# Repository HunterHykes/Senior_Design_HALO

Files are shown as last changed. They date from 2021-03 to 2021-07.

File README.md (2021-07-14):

# Senior_Design_HALO

This is the repository for the Hard Hat Ambient Liability Observer (H.A.L.O.) I assisted in developing for my senior design project at the University of Akron from Spring 2020 - Spring 2021.

<p align="center">
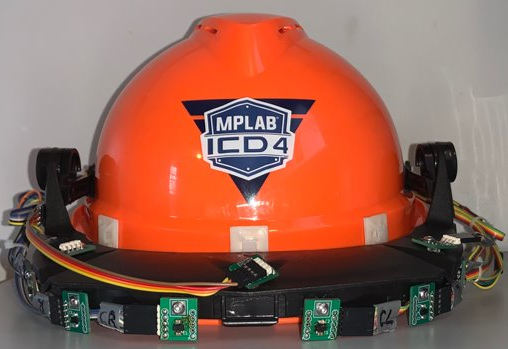
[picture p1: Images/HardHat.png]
  
  
<p align="center">H.A.L.O. attached to a hard hat.</p>
</p>

<p align="center">
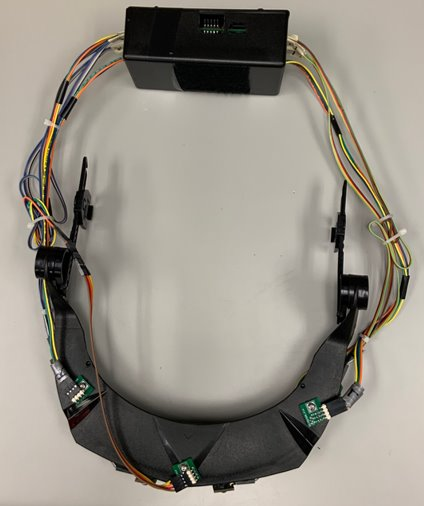
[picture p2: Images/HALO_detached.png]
  
  
<p align="center">H.A.L.O. detached from a hard hat.</p>
</p>

## What the H.A.L.O. Does
This product is a hard hat attachment which utilizes six time-of-flight (ToF) sensors to detect hazards within a 1.5m radius from the wearer's head with a 150° field of view.

<p align="center">
  
  
<p align="center">H.A.L.O. Time-of-Flight Board.</p>
</p>

Dependent on the distance between the user and the hazard, some RGB LEDs placed near the brim of the hard hat will turn on and change hue from yellow to red as objects approach. This enhances the awareness of the user of potential hazards.

<p align="center">
  
  
<p align="center">H.A.L.O. RGB LED Board.</p>
</p>

In the event that the user hits their head either from a collision from walking or perhaps from slipping and falling, an on-board accelerometer will detect the impact severity.

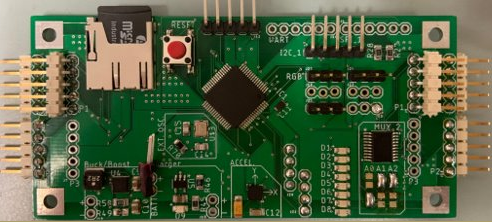
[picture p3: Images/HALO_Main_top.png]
H.A.L.O. Main Board (top).

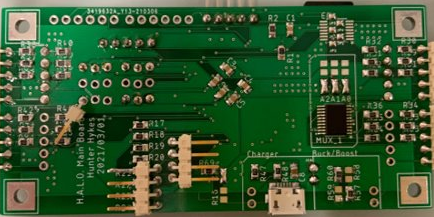
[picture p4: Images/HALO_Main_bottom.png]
H.A.L.O. Main Board (bottom).


If this impact is determined to pose a concussion threat to the user, the accelerometer data is logged to a .csv file on a micro-SD card, which can then be used to assess health-related concerns.

## Images

<p align="center">
  
  
<p align="center">H.A.L.O. being worn by myself.</p>
</p>

<!--- ![H.A.L.O. attached to a hard hat.](https://github.com/HunterHykes/Senior_Design_HALO/raw/main/Images/HardHat.png) --->
<!--- ![H.A.L.O. detached from a hard hat.](https://github.com/HunterHykes/Senior_Design_HALO/raw/main/Images/HALO_detached.png) --->
<!--- ![H.A.L.O. being worn by myself.](https://github.com/HunterHykes/Senior_Design_HALO/raw/main/Images/HALO.JPG) --->
<!--- ![H.A.L.O. Time-of-Flight Board.](https://github.com/HunterHykes/Senior_Design_HALO/raw/main/Images/HALO_ToF.png) --->
<!--- ![H.A.L.O. RGB LED Board.](https://github.com/HunterHykes/Senior_Design_HALO/raw/main/Images/HALO_RGB.png) --->

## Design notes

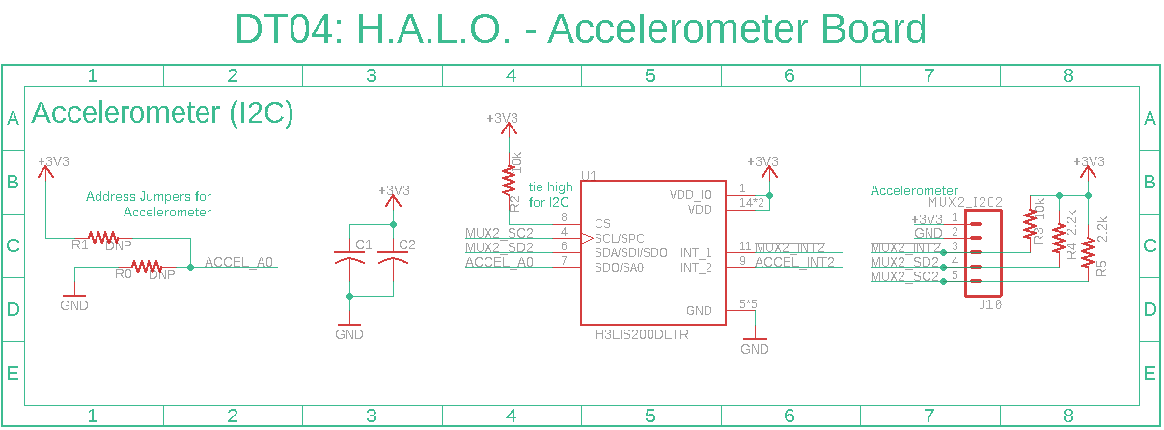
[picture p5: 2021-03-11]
Boards/DT04_Schematic_Images/2021-02-18_HALO_Accel_Board.png

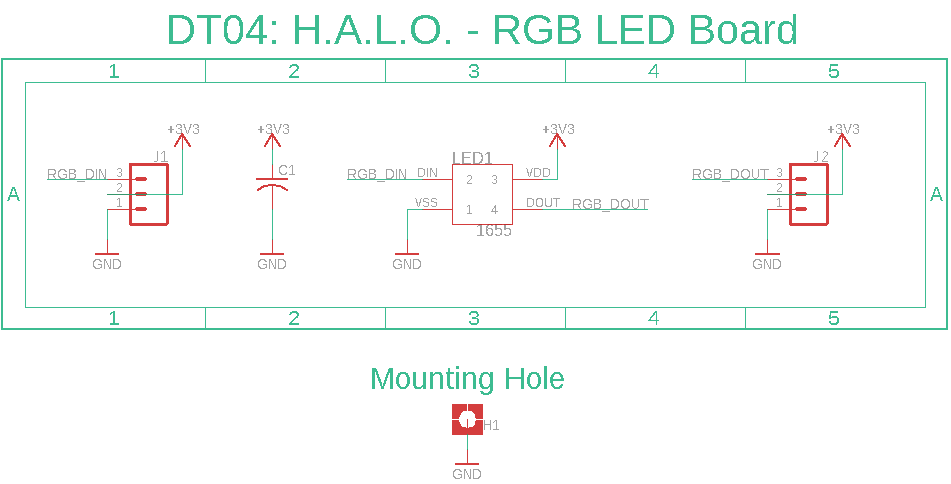
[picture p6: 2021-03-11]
Boards/DT04_Schematic_Images/RGB_Board.png

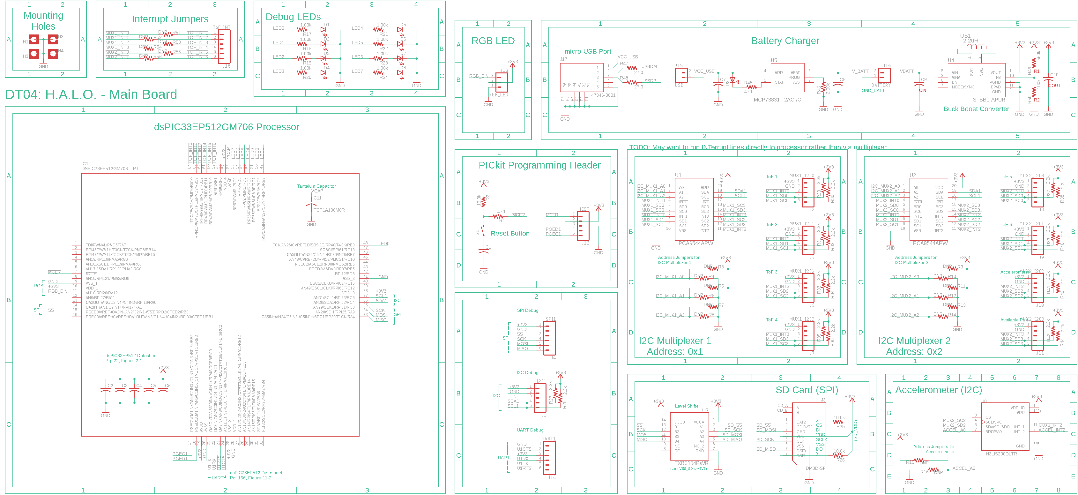
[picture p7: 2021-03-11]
Boards/DT04_Schematic_Images/Main_Board.png

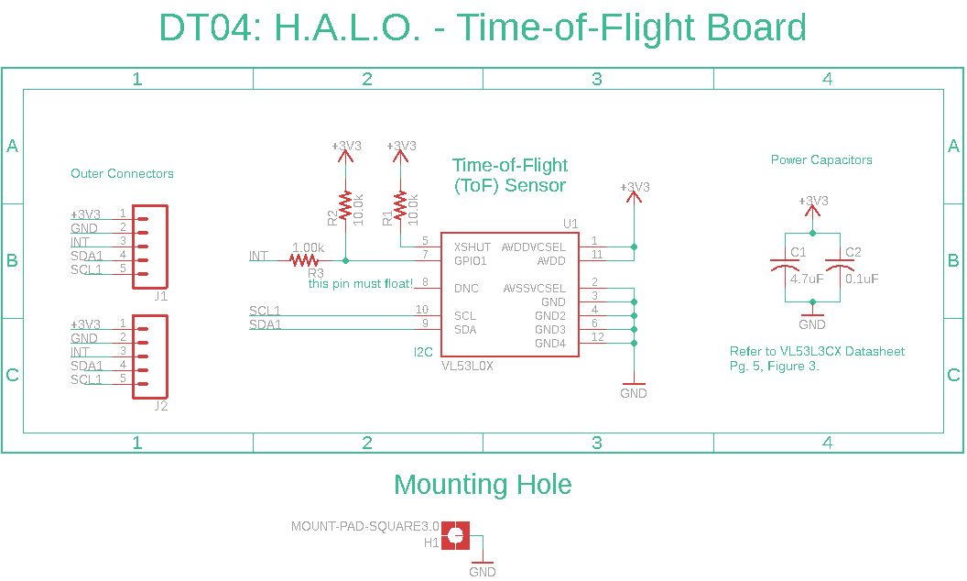
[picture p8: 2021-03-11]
Boards/DT04_Schematic_Images/ToF_Board.png

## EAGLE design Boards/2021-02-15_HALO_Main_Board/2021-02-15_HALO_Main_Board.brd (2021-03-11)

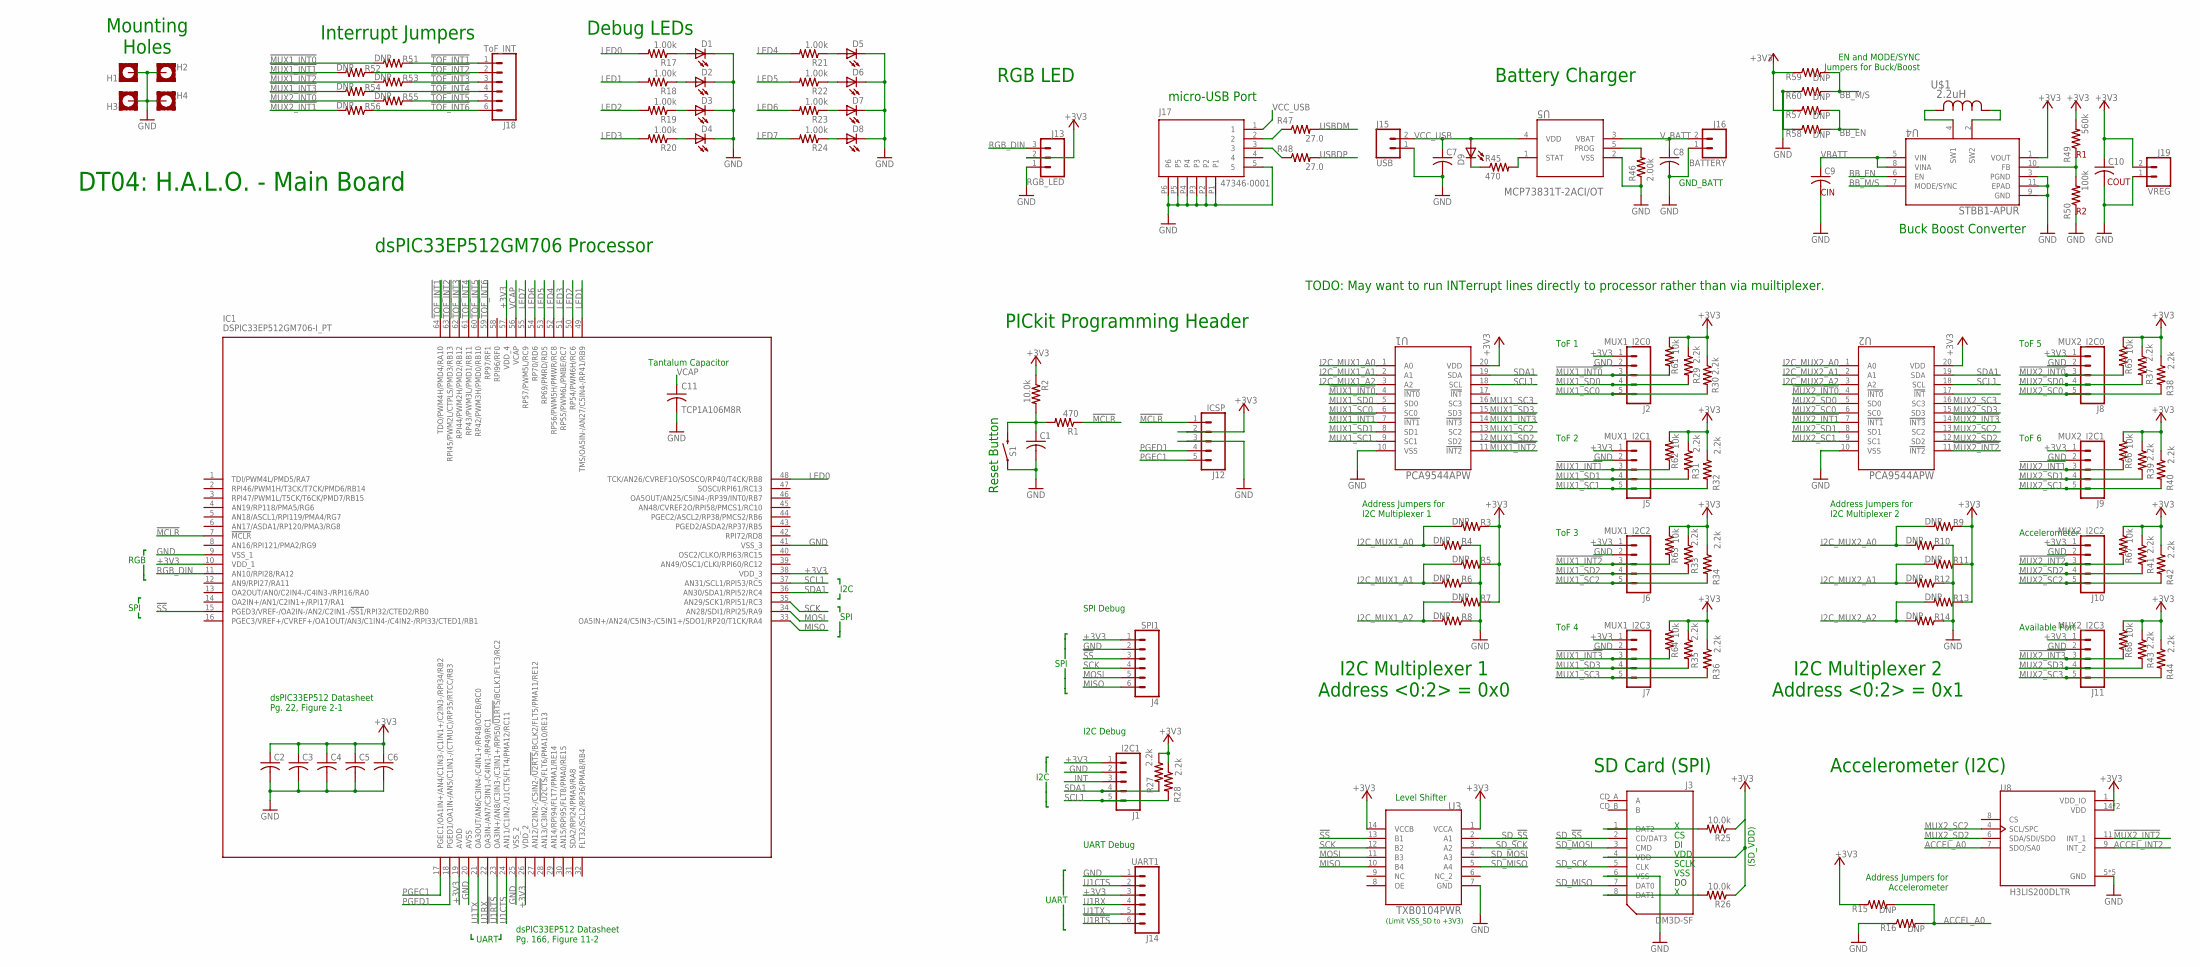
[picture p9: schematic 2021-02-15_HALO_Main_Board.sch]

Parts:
C1, C2, C3, C4, C5, C6: 0.1uF; C0805
C7, C8: 4.7uF; C0805
C9: 10uF; C0805
C10: 22uF; C0805
C11: TCP1A106M8R; TCP_ROM
D1, D2, D3, D4, D5, D6, D7, D8, D9: CHIP-LED0805
H1, H2, H3, H4: MOUNT-PAD-SQUARE3.0; 3,0-PAD-SQUARE
IC1: DSPIC33EP512GM706-I_PT; QFP50P1200X1200X120-64N
J1: I2C1; 1X05
J2: MUX1_I2C0; 1X05
J3: DM3D-SF; SD_CARD
J4: SPI1; 1X06
J5: MUX1_I2C1; 1X05
J6: MUX1_I2C2; 1X05
J7: MUX1_I2C3; 1X05
J8: MUX2_I2C0; 1X05
J9: MUX2_I2C1; 1X05
J10: MUX2_I2C2; 1X05
J11: MUX2_I2C3; 1X05
J12: ICSP; 1X05
J13: RGB_LED; 1X03_LOCK
J14: UART1; 1X06
J15: USB; 1X02
J16: BATTERY; 1X02
J17: 47346-0001; MICRO_USB; PARTNO AS-ITM-00021
J18: ToF_INT; 1X06
J19: VREG; 1X02
R1, R45: 470; R0805
R2, R25, R26: 10.0k; R0805
R3, R4, R5, R6, R7, R8, R9, R10, R11, R12, R13, R14, R15, R16, R51, R52, R53, R54, R55, R56, R57, R58, R59, R60: DNP; R0805
R17, R18, R19, R20, R21, R22, R23, R24: 1.00k; R0805
R27, R28, R29, R30, R31, R32, R33, R34, R35, R36, R37, R38, R39, R40, R41, R42, R43, R44: 2.2k; R0805
R46: 2.00k; R0805
R47, R48: 27.0; R0805
R49: 560k; R0805
R50: 100k; R0805
R61, R62, R63, R64, R65, R66, R67, R68: 10k; R0805
S1: SWITCH-MOMENTARY-2SMD-4; TACTILE_SWITCH_TALL
U1, U2: PCA9544APW; SOT360-1_NXP
U3: TXB0104PWR; PW14
U4: STBB1-APUR; SON_B1-APUR_STM
U5: MCP73831T-2ACI/OT; SOT-23-5_MC_MCH
U8: H3LIS200DLTR; PQFN50P300X300X100-16N
U$1: 2.2uH; IND_4028_TDK

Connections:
!MCLR: IC1.7 (!MCLR), J12.1, R1.1
!MUX1_INT0: J2.3, R51.2, R61.2, U1.4 (!INT0)
!MUX1_INT1: J5.3, R52.2, R62.2, U1.7 (!INT1)
!MUX1_INT2: J6.3, R53.2, R63.2, U1.11 (!INT2)
!MUX1_INT3: J7.3, R54.2, R64.2, U1.14 (!INT3)
!MUX2_INT0: J8.3, R55.2, R65.2, U2.4 (!INT0)
!MUX2_INT1: J9.3, R56.2, R66.2, U2.7 (!INT1)
!MUX2_INT2: J10.3, R67.2, U2.11 (!INT2), U8.11 (INT_1)
!MUX2_INT3: J11.3, R68.2, U2.14 (!INT3)
!SS: IC1.15 (PGED3/VREF-/OA2IN-/AN2/C2IN1-/!SS1!/RPI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), J4.3, U3.13 (B1)
!TOF_INT1: IC1.64 (TDO/PWM4H/PMD4/RA10), J18.1, R51.1
!TOF_INT2: IC1.63 (RPI45/PWM2L/CTPLS/PMD3/RB13), J18.2, R52.1
!TOF_INT3: IC1.62 (RPI44/PWM2H/PMD2/RB12), J18.3, R53.1
!TOF_INT4: IC1.61 (RP43/PWM3L/PMD1/RB11), J18.4, R54.1
!TOF_INT5: IC1.60 (RP42/PWM3H/PMD0/RB10), J18.5, R55.1
!TOF_INT6: IC1.59 (RP97/RF1), J18.6, R56.1
!U1RTS: IC1.23 (OA3IN+/AN8/C3IN3-/C3IN1+/RPI50/!U1RTS!/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), J14.6
+3V3: C2.1, C3.1, C4.1, C5.1, C6.1, C10.1, IC1.10 (VDD_1), IC1.19 (AVDD), IC1.26 (VDD_2), IC1.38 (VDD_3), IC1.57 (VDD_4), J1.1, J2.1, J3.4 (VDD), J4.1, J5.1, J6.1, J7.1, J8.1, J9.1, J10.1, J11.1, J12.2, J13.2, J14.3, J19.2, R2.1, R3.1, R5.1, R7.1, R9.1, R11.1, R13.1, R15.1, R25.1, R26.1, R27.1, R28.1, R29.1, R30.1, R31.1, R32.1, R33.1, R34.1, R35.1, R36.1, R37.1, R38.1, R39.1, R40.1, R41.1, R42.1, R43.1, R44.1, R49.2, R57.1, R59.1, R61.1, R62.1, R63.1, R64.1, R65.1, R66.1, R67.1, R68.1, U1.20 (VDD), U2.20 (VDD), U3.1 (VCCA), U3.14 (VCCB), U4.1 (VOUT), U8.1 (VDD_IO), U8.14 (VDD), U8.15 (VDD)
ACCEL_A0: R15.2, R16.2, U8.7 (SDO/SA0)
ACCEL_INT2: U8.9 (INT_2)
BB_EN: R57.2, R58.2, U4.6 (EN)
BB_M/S: R59.2, R60.2, U4.7 (MODE/SYNC)
GND: C1.2, C2.2, C3.2, C4.2, C5.2, C6.2, C7.2, C8.2, C9.2, C10.2, C11.2, D1.C, D2.C, D3.C, D4.C, D5.C, D6.C, D7.C, D8.C, H1.B3,0, H2.B3,0, H3.B3,0, H4.B3,0, IC1.9 (VSS_1), IC1.20 (AVSS), IC1.25 (VSS_2), IC1.41 (VSS_3), J1.2, J2.2, J3.6 (VSS), J4.2, J5.2, J6.2, J7.2, J8.2, J9.2, J10.2, J11.2, J12.3, J13.1, J14.1, J15.1, J16.1, J17.5, J17.P1, J17.P2, J17.P3, J17.P4, J17.P5, J17.P6, J19.1, R4.1, R6.1, R8.1, R10.1, R12.1, R14.1, R16.1, R46.1, R50.1, R58.1, R60.1, S1.A2 (1), U1.10 (VSS), U2.10 (VSS), U3.7 (GND), U4.3 (PGND), U4.9 (GND), U4.11 (EPAD), U5.2 (VSS), U8.5 (GND), U8.10 (GND), U8.12 (GND), U8.13 (GND), U8.16 (GND)
I2C_MUX1_A0: R3.2, R4.2, U1.1 (A0)
I2C_MUX1_A1: R5.2, R6.2, U1.2 (A1)
I2C_MUX1_A2: R7.2, R8.2, U1.3 (A2)
I2C_MUX2_A0: R9.2, R10.2, U2.1 (A0)
I2C_MUX2_A1: R11.2, R12.2, U2.2 (A1)
I2C_MUX2_A2: R13.2, R14.2, U2.3 (A2)
INT: J1.3
LED0: IC1.48 (TCK/AN26/CVREF1O/SOSCO/RP40/T4CK/RB8), R17.2
LED1: IC1.49 (TMS/OA5IN-/AN27/C5IN4-/RP41/RB9), R18.2
LED2: IC1.50 (RP54/PWM6H/RC6), R19.2
LED3: IC1.51 (RP55/PWM6L/PMBE/RC7), R20.2
LED4: IC1.52 (RP56/PWM5H/PMWR/RC8), R21.2
LED5: IC1.53 (RP69/PMRD/RD5), R22.2
LED6: IC1.54 (RP70/RD6), R23.2
LED7: IC1.55 (RP57/PWM5L/RC9), R24.2
MISO: IC1.33 (OA5IN+/AN24/C5IN3-/C5IN1+/SDO1/RP20/T1C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), J4.6, U3.10 (B4)
MOSI: IC1.34 (AN28/SDI1/RPI25/RA9), J4.5, U3.11 (B3)
MUX1_SC0: J2.5, R30.2, U1.6 (SC0)
MUX1_SC1: J5.5, R32.2, U1.9 (SC1)
MUX1_SC2: J6.5, R34.2, U1.13 (SC2)
MUX1_SC3: J7.5, R36.2, U1.16 (SC3)
MUX1_SD0: J2.4, R29.2, U1.5 (SD0)
MUX1_SD1: J5.4, R31.2, U1.8 (SD1)
MUX1_SD2: J6.4, R33.2, U1.12 (SD2)
MUX1_SD3: J7.4, R35.2, U1.15 (SD3)
MUX2_SC0: J8.5, R38.2, U2.6 (SC0)
MUX2_SC1: J9.5, R40.2, U2.9 (SC1)
MUX2_SC2: J10.5, R42.2, U2.13 (SC2), U8.4 (SCL/SPC)
MUX2_SC3: J11.5, R44.2, U2.16 (SC3)
MUX2_SD0: J8.4, R37.2, U2.5 (SD0)
MUX2_SD1: J9.4, R39.2, U2.8 (SD1)
MUX2_SD2: J10.4, R41.2, U2.12 (SD2), U8.6 (SDA/SDI/SDO)
MUX2_SD3: J11.4, R43.2, U2.15 (SD3)
unnamed: C1.1, R1.2, R2.2, S1.B2 (2)
unnamed: J3.8 (DAT1), R26.2
unnamed: J3.1 (DAT2), R25.2
unnamed: D1.A, R17.1
unnamed: J17.2, R47.1
unnamed: D2.A, R18.1
unnamed: D9.C, R45.1
unnamed: R49.1, R50.2, U4.10 (FB)
unnamed: D3.A, R19.1
unnamed: D4.A, R20.1
unnamed: D5.A, R21.1
unnamed: D6.A, R22.1
unnamed: D7.A, R23.1
unnamed: D8.A, R24.1
unnamed: R45.2, U5.1 (STAT)
unnamed: J17.3, R48.1
unnamed: U4.4 (SW1), U$1.2
unnamed: R46.2, U5.5 (PROG)
unnamed: U4.2 (SW2), U$1.1
PGEC1: IC1.17 (PGEC1/OA1IN+/AN4/C1IN3-/C1IN1+/C2IN3-/R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), J12.5
PGED1: IC1.18 (PGED1/OA1IN-/AN5/C1IN1-/(CTMUC)/RP35/RT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), J12.4
RGB_DIN: IC1.11 (AN10/RPI28/RA12), J13.3
SCK: IC1.35 (AN29/SCK1/RPI51/RC3), J4.4, U3.12 (B2)
SCL1: IC1.37 (AN31/SCL1/RPI53/RC5), J1.5, R28.2, U1.18 (SCL), U2.18 (SCL)
SDA1: IC1.36 (AN30/SDA1/RPI52/RC4), J1.4, R27.2, U1.19 (SDA), U2.19 (SDA)
SD_!SS: J3.2 (CD/DAT3), U3.2 (A1)
SD_MISO: J3.7 (DAT0), U3.5 (A4)
SD_MOSI: J3.3 (CMD), U3.4 (A3)
SD_SCK: J3.5 (CLK), U3.3 (A2)
U1CTS: IC1.24 (AN11/C1IN2-/U1CTS/FLT4/PMA12/RC11), J14.2
U1RX: IC1.22 (OA3IN-/AN7/C3IN1-/C4IN1-/RP49/RC1), J14.4
U1TX: IC1.21 (OA3OUT/AN6/C3IN4-/C4IN1+/RP48/OCFB/RC0), J14.5
USBDM: R47.2
USBDP: R48.2
VBATT: C9.1, U4.5 (VIN), U4.8 (VINA)
VCAP: C11.1, IC1.56 (VCAP)
VCC_USB: C7.1, D9.A, J15.2, J17.1, U5.4 (VDD)
V_BATT: C8.1, J16.2, U5.3 (VBAT)

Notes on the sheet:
┓ SPI ┃ ┛
┓ I2C ┛
Reset Button
VDD
SCLK
VSS
SD Card (SPI)
Address Jumpers for I2C Multiplexer 1
Address Jumpers for I2C Multiplexer 2
I2C Debug
SPI Debug
I2C Multiplexer 1 Address <0:2> = 0x0
I2C Multiplexer 2 Address <0:2> = 0x1
ToF 1
ToF 2
ToF 3
ToF 4
ToF 5
ToF 6
Accelerometer
Available Port
TODO: May want to run INTerrupt lines directly to processor rather than via muiltiplexer.
DT04: H.A.L.O. - Main Board
dsPIC33EP512 Datasheet Pg. 22, Figure 2-1
PICkit Programming Header
Debug LEDs
dsPIC33EP512 Datasheet Pg. 166, Figure 11-2
┗ UART┛
Level Shifter
(Limit VSS_SD to +3V3)
(SD_VDD)
RGB LED
Battery Charger
Buck Boost Converter
GND_BATT
Accelerometer (I2C)
Address Jumpers for Accelerometer
UART Debug
┏ ┃ I2C ┃ ┃ ┗
┏ ┃ ┃ SPI ┃ ┃ ┗

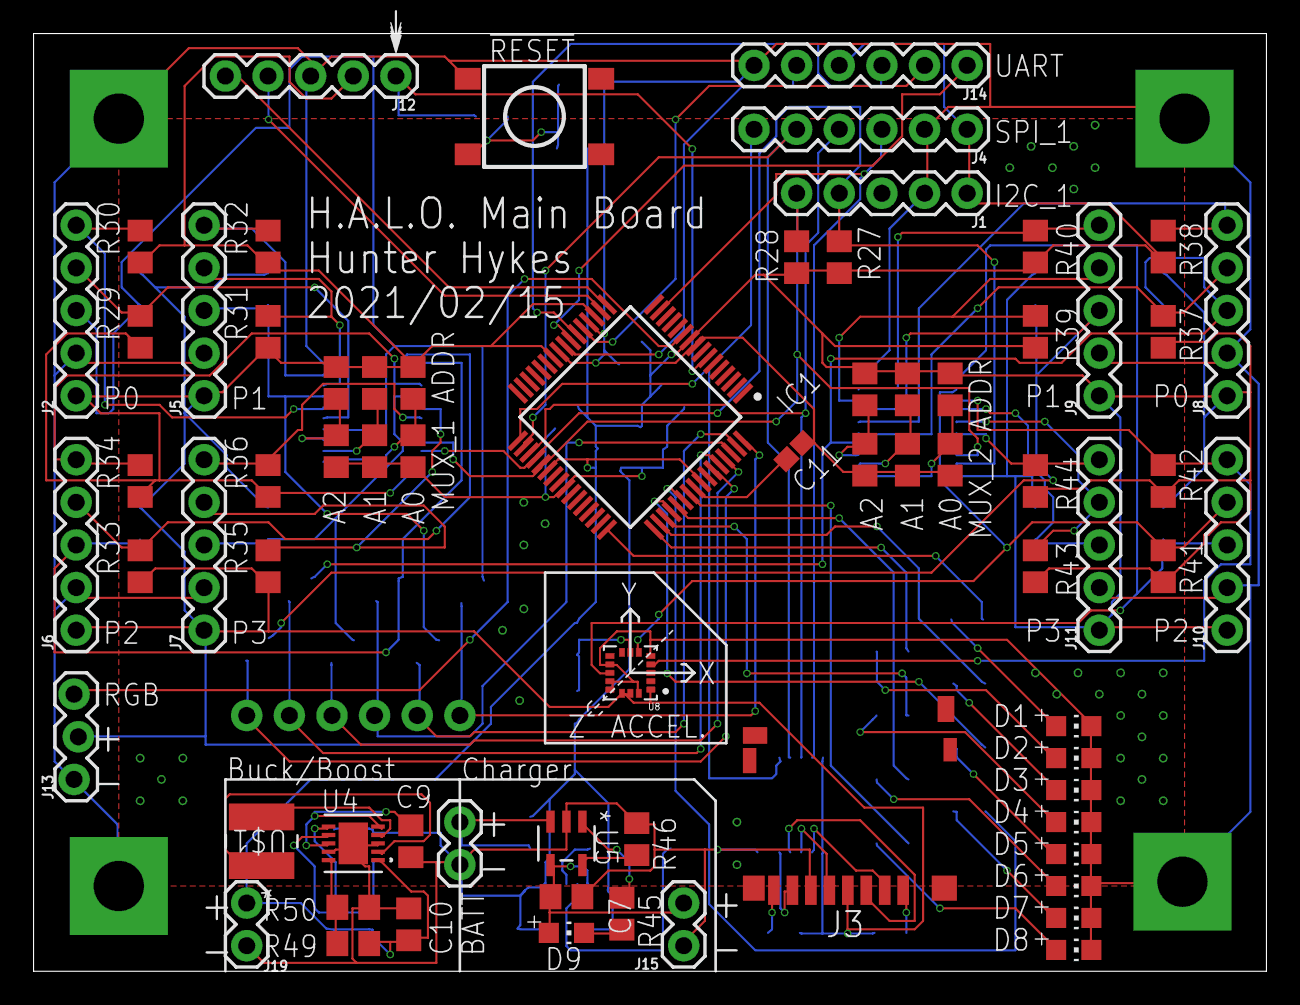
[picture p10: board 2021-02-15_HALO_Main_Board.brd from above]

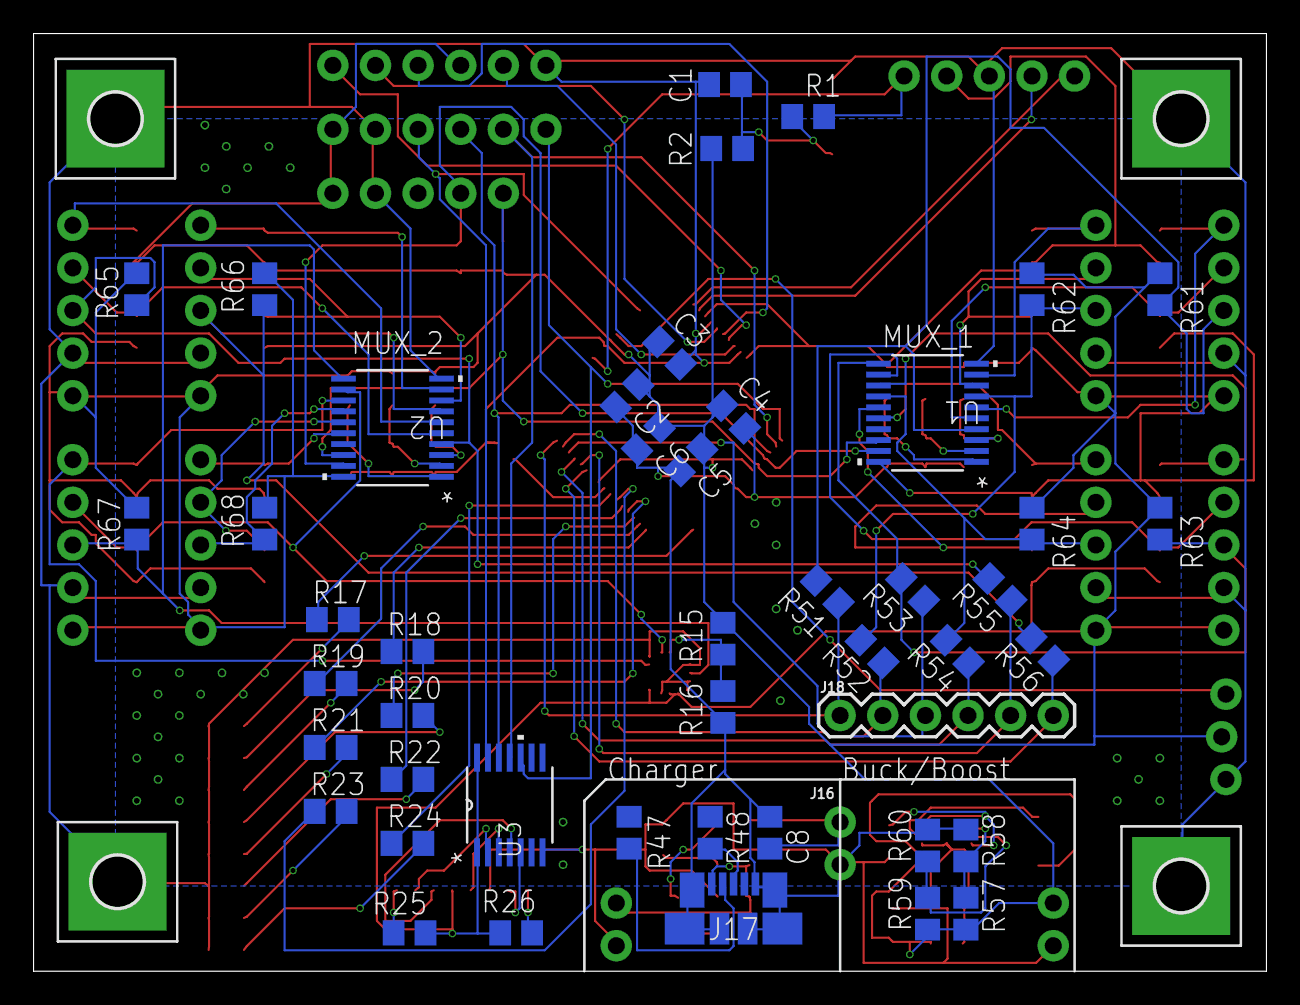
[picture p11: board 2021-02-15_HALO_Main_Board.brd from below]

Board: 2 copper layers, 73.5 x 55.9 mm, 120 parts (50 on the bottom side), 90 nets.

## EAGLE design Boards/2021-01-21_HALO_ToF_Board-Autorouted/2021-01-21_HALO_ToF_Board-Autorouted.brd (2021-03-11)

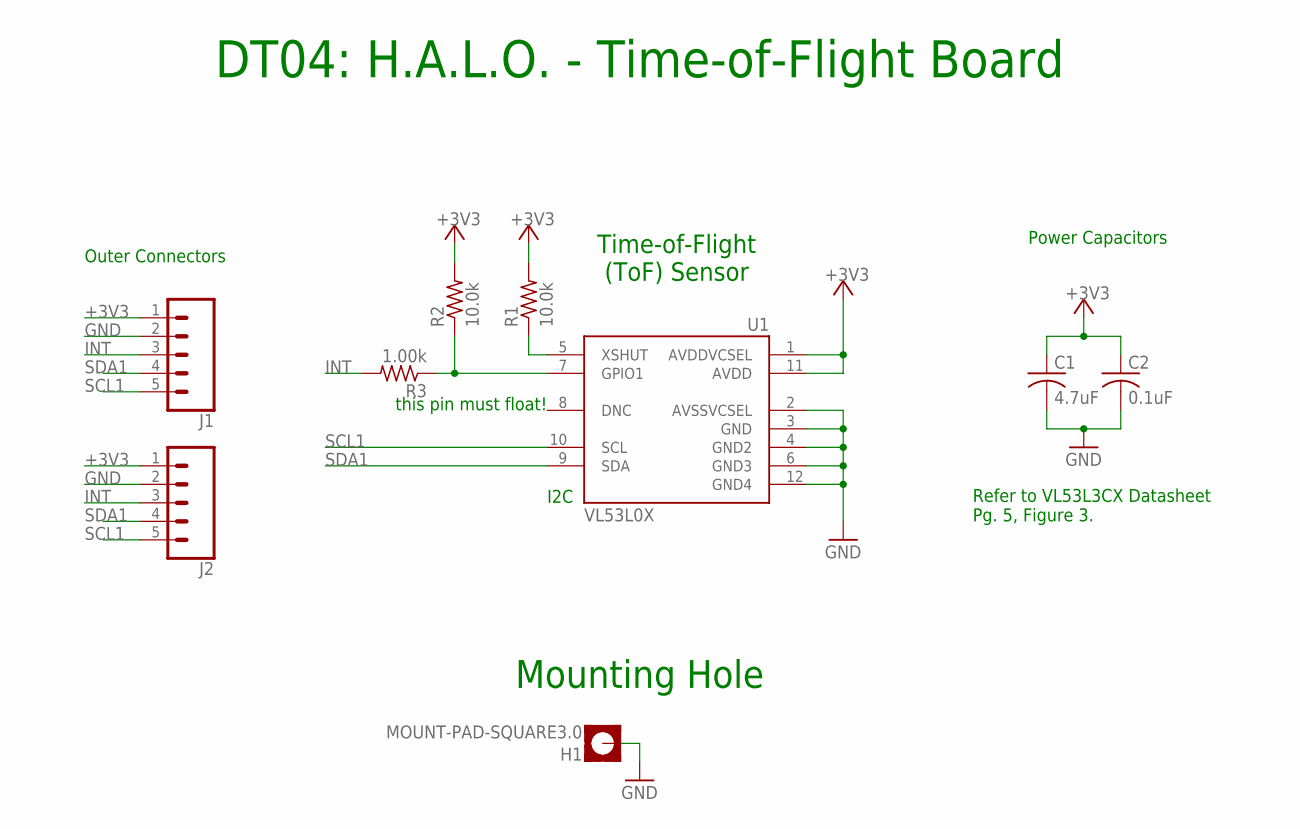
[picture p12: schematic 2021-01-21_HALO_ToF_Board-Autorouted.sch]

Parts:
C1: 4.7uF; C0805
C2: 0.1uF; C0805
H1: MOUNT-PAD-SQUARE3.0; 3,0-PAD-SQUARE
J1, J2: CONN_05; 1X05
R1, R2: 10.0k; R0805
R3: 1.00k; R0805
U1: VL53L0X

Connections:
+3V3: C1.1, C2.1, J1.1, J2.1, R1.2, R2.2, U1.1 (AVDDVCSEL), U1.11 (AVDD)
GND: C1.2, C2.2, H1.B3,0, J1.2, J2.2, U1.2 (AVSSVCSEL), U1.3 (GND), U1.4 (GND2), U1.6 (GND3), U1.12 (GND4)
INT: J1.3, J2.3, R3.2
unnamed: R1.1, U1.5 (XSHUT)
unnamed: R2.1, R3.1, U1.7 (GPIO1)
SCL1: J1.5, J2.5, U1.10 (SCL)
SDA1: J1.4, J2.4, U1.9 (SDA)

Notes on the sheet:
Outer Connectors
Refer to VL53L3CX Datasheet Pg. 5, Figure 3.
Power Capacitors
Time-of-Flight (ToF) Sensor
I2C
this pin must float!
DT04: H.A.L.O. - Time-of-Flight Board
Mounting Hole

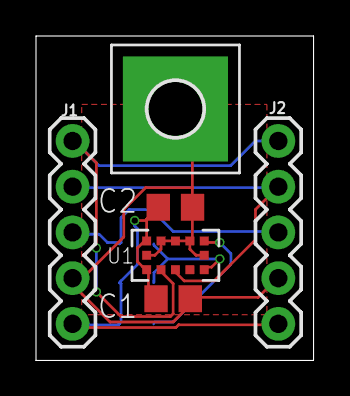
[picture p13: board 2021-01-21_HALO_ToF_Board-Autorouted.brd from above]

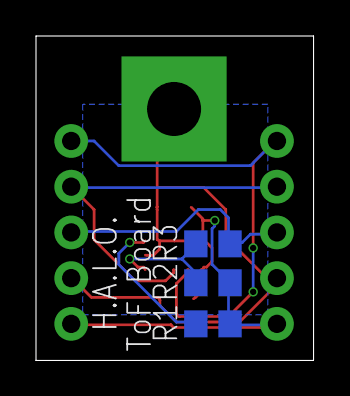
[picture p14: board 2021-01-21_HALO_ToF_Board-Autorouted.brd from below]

Board: 2 copper layers, 15.4 x 18.0 mm, 9 parts (3 on the bottom side), 7 nets.

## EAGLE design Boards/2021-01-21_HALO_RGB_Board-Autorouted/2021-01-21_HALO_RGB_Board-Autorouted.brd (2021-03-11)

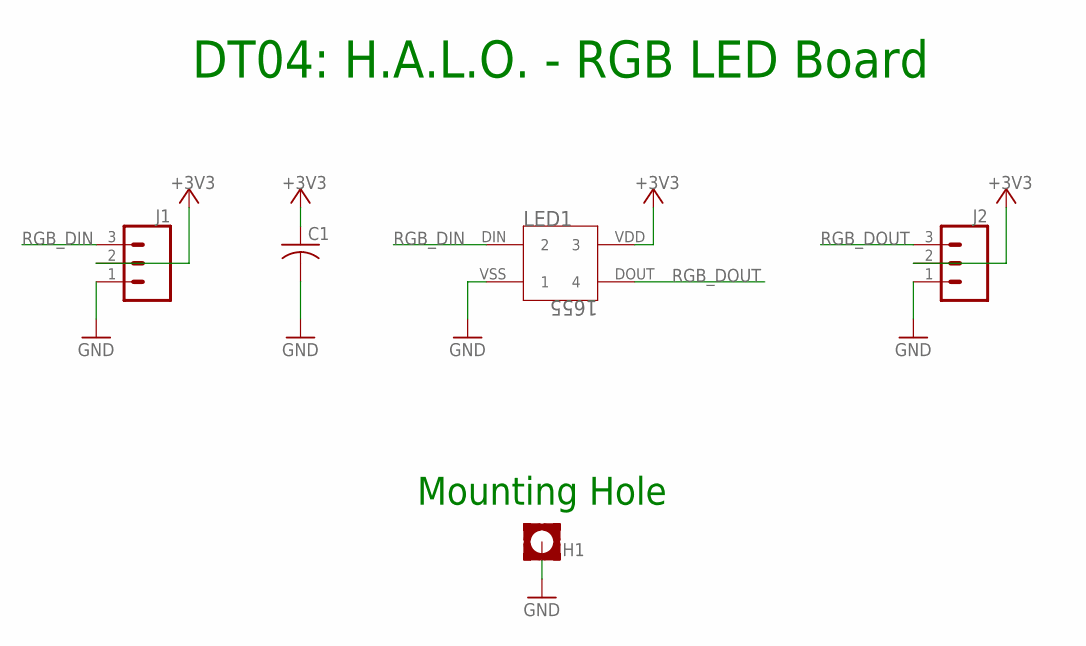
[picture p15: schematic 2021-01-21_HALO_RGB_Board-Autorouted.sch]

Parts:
C1: 1uF; C0805
H1: MOUNT-PAD-SQUARE3.0; 3,0-PAD-SQUARE
J1, J2: CONN_03LOCK; 1X03_LOCK
LED1: 1655; LED_1655_ADA

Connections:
+3V3: C1.1, J1.2, J2.2, LED1.VDD (3)
GND: C1.2, H1.B3,0, J1.1, J2.1, LED1.VSS (1)
RGB_DIN: J1.3, LED1.DIN (2)
RGB_DOUT: J2.3, LED1.DOUT (4)

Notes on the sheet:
DT04: H.A.L.O. - RGB LED Board
Mounting Hole

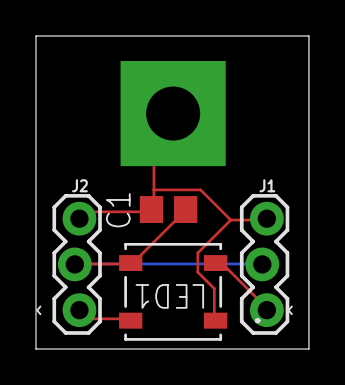
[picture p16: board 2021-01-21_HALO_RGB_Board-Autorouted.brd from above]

Board: 2 copper layers, 15.2 x 17.4 mm, 5 parts (1 on the bottom side), 4 nets.

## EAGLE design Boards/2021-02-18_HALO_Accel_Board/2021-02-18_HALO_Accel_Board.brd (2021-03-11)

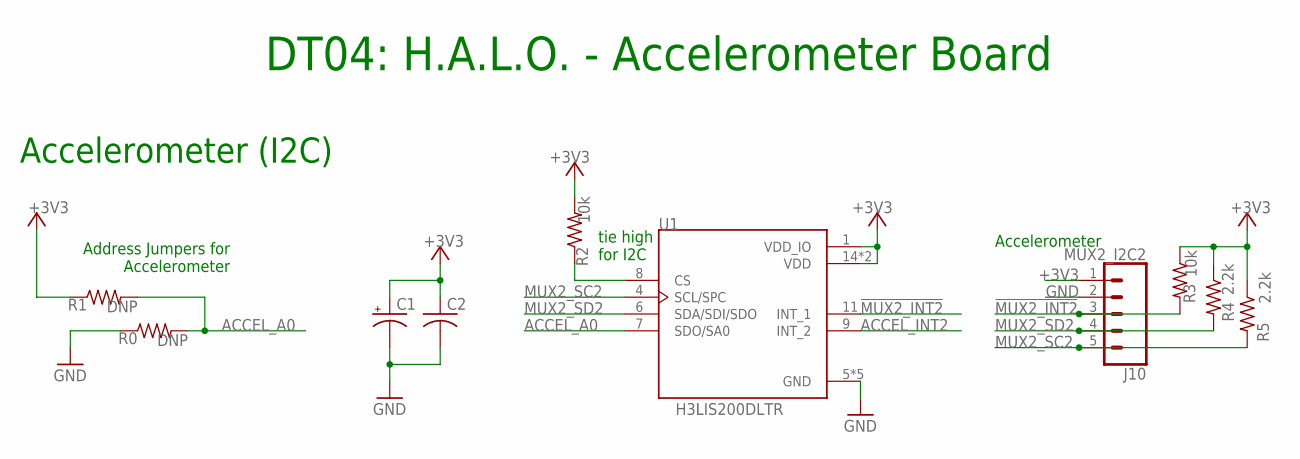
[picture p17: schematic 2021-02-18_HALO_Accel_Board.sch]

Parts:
C1: 10uF; EIA3216
C2: 0.1uF; C0805
J10: MUX2_I2C2; 1X05
R0, R1: DNP; R0805
R2, R3: 10k; R0805
R4, R5: 2.2k; R0805
U1: H3LIS200DLTR; PQFN50P300X300X100-16N

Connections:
!MUX2_INT2: J10.3, R3.2, U1.11 (INT_1)
+3V3: C1.+, C2.1, J10.1, R1.1, R2.2, R3.1, R4.1, R5.1, U1.1 (VDD_IO), U1.14 (VDD), U1.15 (VDD)
ACCEL_A0: R0.2, R1.2, U1.7 (SDO/SA0)
ACCEL_INT2: U1.9 (INT_2)
GND: C1.-, C2.2, J10.2, R0.1, U1.5 (GND), U1.10 (GND), U1.12 (GND), U1.13 (GND), U1.16 (GND)
MUX2_SC2: J10.5, R5.2, U1.4 (SCL/SPC)
MUX2_SD2: J10.4, R4.2, U1.6 (SDA/SDI/SDO)
unnamed: R2.1, U1.8 (CS)

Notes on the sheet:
Accelerometer
DT04: H.A.L.O. - Accelerometer Board
Accelerometer (I2C)
Address Jumpers for Accelerometer
tie high for I2C

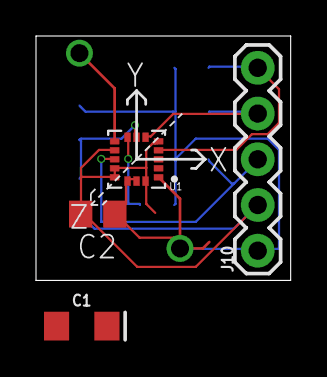
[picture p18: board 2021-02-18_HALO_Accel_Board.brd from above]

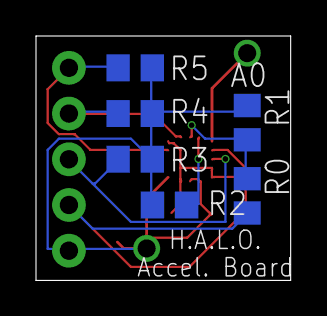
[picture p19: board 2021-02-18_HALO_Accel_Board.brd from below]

Board: 2 copper layers, 14.1 x 13.6 mm, 10 parts (6 on the bottom side), 7 nets.

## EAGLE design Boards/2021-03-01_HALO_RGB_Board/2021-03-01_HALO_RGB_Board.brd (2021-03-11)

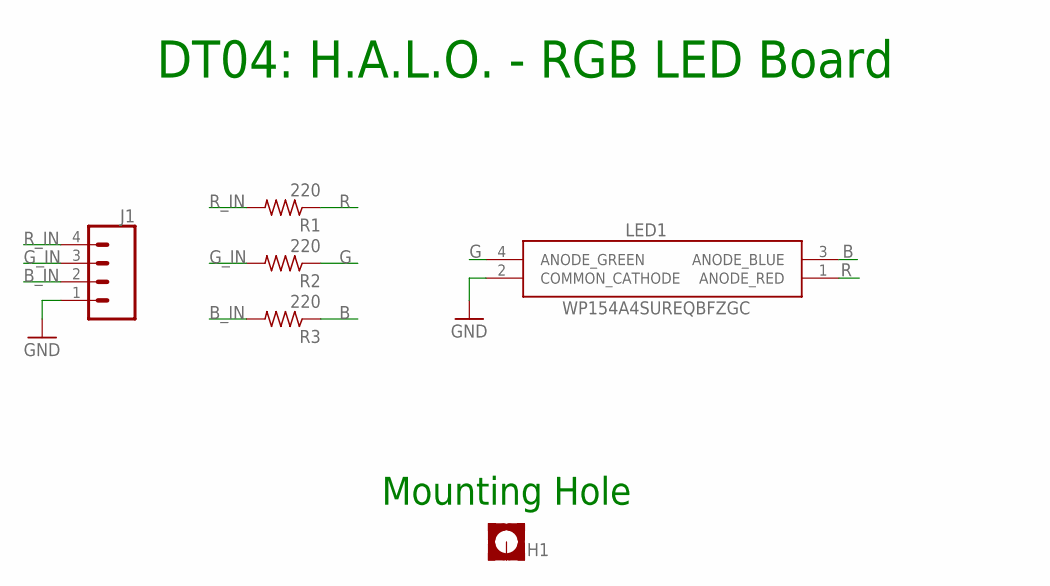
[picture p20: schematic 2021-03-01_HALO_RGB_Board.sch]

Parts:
H1: MOUNT-PAD-SQUARE3.0; 3,0-PAD-SQUARE
J1: CONN_04; 1X04
LED1: WP154A4SUREQBFZGC; L-154A4SUREQBFZGEC
R1, R2, R3: 220; R0805

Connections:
B: LED1.3 (ANODE_BLUE), R3.1
B_IN: J1.2, R3.2
G: LED1.4 (ANODE_GREEN), R2.1
GND: J1.1, LED1.2 (COMMON_CATHODE)
G_IN: J1.3, R2.2
R: LED1.1 (ANODE_RED), R1.1
R_IN: J1.4, R1.2

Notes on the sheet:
DT04: H.A.L.O. - RGB LED Board
Mounting Hole



Board: 2 copper layers, 15.2 x 16.6 mm, 6 parts (4 on the bottom side), 7 nets.

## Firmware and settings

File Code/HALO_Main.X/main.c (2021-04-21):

/**
  Generated main.c file from MPLAB Code Configurator

  @Company
    Microchip Technology Inc.

  @File Name
    main.c

  @Summary
    This is the generated main.c using PIC24 / dsPIC33 / PIC32MM MCUs.

  @Description
    This source file provides main entry point for system initialization and application code development.
    Generation Information :
        Product Revision  :  PIC24 / dsPIC33 / PIC32MM MCUs - 1.170.0
        Device            :  dsPIC33EP512GM706
    The generated drivers are tested against the following:
        Compiler          :  XC16 v1.61
        MPLAB 	          :  MPLAB X v5.45
*/

/*
    (c) 2020 Microchip Technology Inc. and its subsidiaries. You may use this
    software and any derivatives exclusively with Microchip products.

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
    IN NO EVENT WILL MICROCHIP BE LIABLE FOR ANY INDIRECT, SPECIAL, PUNITIVE,
    INCIDENTAL OR CONSEQUENTIAL LOSS, DAMAGE, COST OR EXPENSE OF ANY KIND
    WHATSOEVER RELATED TO THE SOFTWARE, HOWEVER CAUSED, EVEN IF MICROCHIP HAS
    BEEN ADVISED OF THE POSSIBILITY OR THE DAMAGES ARE FORESEEABLE. TO THE
    FULLEST EXTENT ALLOWED BY LAW, MICROCHIP'S TOTAL LIABILITY ON ALL CLAIMS IN
    ANY WAY RELATED TO THIS SOFTWARE WILL NOT EXCEED THE AMOUNT OF FEES, IF ANY,
    THAT YOU HAVE PAID DIRECTLY TO MICROCHIP FOR THIS SOFTWARE.

    MICROCHIP PROVIDES THIS SOFTWARE CONDITIONALLY UPON YOUR ACCEPTANCE OF THESE
    TERMS.
*/

/**
  Section: Included Files
*/
#include <xc.h>
#include <stdbool.h>
#include <stdlib.h>

#define FCY 4000000UL // clock frequency
#include <libpic30.h>

#include "mcc_generated_files/mcc.h"
//#include "mcc_generated_files/system.h"
#include "mcc_generated_files/fatfs/fatfs_demo.h"
#include "mcc_generated_files/pwm_module_features.h"
#include "I2C_Handler.h"
#include "Initialize.h"

// Address Definitions
#define MUX_0 0x70
#define MUX_1 0x71

// number of ToF sensors
#define NUM_TOF 6

// pairing of mux numbers and port numbers
typedef struct {
    uint8_t mux;
    uint8_t port;
} muxPort_t;

// store (mux, port) pairs in an array
muxPort_t ToF[NUM_TOF] = {
    {0x00, 0x00},   // Left Center  --> MID LED
    {0x00, 0x01},   // Left         --> LEFT LED
    {0x00, 0x02},   // Left Left    --> LEFT LED
    {0x01, 0x00},   // Right Center --> MID LED
    {0x01, 0x01},   // Right        --> RIGHT LED
    {0x01, 0x02}    // Right Right  --> RIGHT LED
};

// LEFT LED == 0, MID LED == 1, RIGHT LED == 2
int LEDs[NUM_TOF] = {
    1, 0, 0, 1, 2, 2
};

/* * * * * * * * * * * RGB LED Color Definitions * * * * * * * * * * */
// These are utilizing the same I/O pins as the on-board LEDs
/*
 * (0x01) LED1 <==> L/R RED
 * (0x02) LED2 <==> L/R GRN
 * (0x04) LED3 <==> L/R BLU
 * (0x08) LED4 <==> R ENABLE (ENABLEs are active LOW)
 * (0x10) LED5 <==> L ENABLE
 * (0x20) LED6 <==> MID RED
 * (0x40) LED7 <==> MID GRN
 * (0x80) LED8 <==> MID BLU (MID LED has no ENABLE, is tied to GND)
*/
#define LR_RED  0x01
#define LR_GRN  0x02
#define LR_BLU  0x04
#define LR_YLW  0x03
#define LR_PRP  0x05
#define LR_ON   0x00 // both L and R on
#define R_ON    0x00
#define R_OFF   0x10
#define L_ON    0x00
#define L_OFF   0x08
#define MID_RED 0x20
#define MID_GRN 0x40
#define MID_BLU 0x80
#define MID_YLW 0x60
#define MID_PRP 0xA0

typedef enum { LED_L, LED_C, LED_R } LED_posn;


/* * * * * * * * * * * ToF Sensor Definitions * * * * * * * * * * */
# define MAX_DISTANCE 1500 // 1500mm = 1.5m, the maximum range of interest

#define VL53L0X_I2CADDR 0x29
// Record the current time to check an upcoming timeout against
#define startTimeout() (timeout_start_ms = millis())
// Check if timeout is enabled (set to nonzero value) and has expired
#define checkTimeoutExpired() (io_timeout > 0 && ((uint16_t)millis() - timeout_start_ms) > io_timeout)
// Decode VCSEL (vertical cavity surface emitting laser) pulse period in PCLKs
// from register value
// based on VL53L0X_decode_vcsel_period()
#define decodeVcselPeriod(reg_val)      (((reg_val) + 1) << 1)
// Encode VCSEL pulse period register value from period in PCLKs
// based on VL53L0X_encode_vcsel_period()
#define encodeVcselPeriod(period_pclks) (((period_pclks) >> 1) - 1)
// Calculate macro period in *nanoseconds* from VCSEL period in PCLKs
// based on VL53L0X_calc_macro_period_ps()
// PLL_period_ps = 1655; macro_period_vclks = 2304
#define calcMacroPeriod(vcsel_period_pclks) ((((uint32_t)2304 * (vcsel_period_pclks) * 1655) + 500) / 1000)

enum regAddr {
    SYSRANGE_START                              = 0x00,

    SYSTEM_THRESH_HIGH                          = 0x0C,
    SYSTEM_THRESH_LOW                           = 0x0E,

    SYSTEM_SEQUENCE_CONFIG                      = 0x01,
    SYSTEM_RANGE_CONFIG                         = 0x09,
    SYSTEM_INTERMEASUREMENT_PERIOD              = 0x04,

    SYSTEM_INTERRUPT_CONFIG_GPIO                = 0x0A,

    GPIO_HV_MUX_ACTIVE_HIGH                     = 0x84,

    SYSTEM_INTERRUPT_CLEAR                      = 0x0B,

    RESULT_INTERRUPT_STATUS                     = 0x13,
    RESULT_RANGE_STATUS                         = 0x14,

    RESULT_CORE_AMBIENT_WINDOW_EVENTS_RTN       = 0xBC,
    RESULT_CORE_RANGING_TOTAL_EVENTS_RTN        = 0xC0,
    RESULT_CORE_AMBIENT_WINDOW_EVENTS_REF       = 0xD0,
    RESULT_CORE_RANGING_TOTAL_EVENTS_REF        = 0xD4,
    RESULT_PEAK_SIGNAL_RATE_REF                 = 0xB6,

    ALGO_PART_TO_PART_RANGE_OFFSET_MM           = 0x28,

    I2C_SLAVE_DEVICE_ADDRESS                    = 0x8A,

    MSRC_CONFIG_CONTROL                         = 0x60,

    PRE_RANGE_CONFIG_MIN_SNR                    = 0x27,
    PRE_RANGE_CONFIG_VALID_PHASE_LOW            = 0x56,
    PRE_RANGE_CONFIG_VALID_PHASE_HIGH           = 0x57,
    PRE_RANGE_MIN_COUNT_RATE_RTN_LIMIT          = 0x64,

    FINAL_RANGE_CONFIG_MIN_SNR                  = 0x67,
    FINAL_RANGE_CONFIG_VALID_PHASE_LOW          = 0x47,
    FINAL_RANGE_CONFIG_VALID_PHASE_HIGH         = 0x48,
    FINAL_RANGE_CONFIG_MIN_COUNT_RATE_RTN_LIMIT = 0x44,

    PRE_RANGE_CONFIG_SIGMA_THRESH_HI            = 0x61,
    PRE_RANGE_CONFIG_SIGMA_THRESH_LO            = 0x62,

    PRE_RANGE_CONFIG_VCSEL_PERIOD               = 0x50,
    PRE_RANGE_CONFIG_TIMEOUT_MACROP_HI          = 0x51,
    PRE_RANGE_CONFIG_TIMEOUT_MACROP_LO          = 0x52,

    SYSTEM_HISTOGRAM_BIN                        = 0x81,
    HISTOGRAM_CONFIG_INITIAL_PHASE_SELECT       = 0x33,
    HISTOGRAM_CONFIG_READOUT_CTRL               = 0x55,

    FINAL_RANGE_CONFIG_VCSEL_PERIOD             = 0x70,
    FINAL_RANGE_CONFIG_TIMEOUT_MACROP_HI        = 0x71,
    FINAL_RANGE_CONFIG_TIMEOUT_MACROP_LO        = 0x72,
    CROSSTALK_COMPENSATION_PEAK_RATE_MCPS       = 0x20,

    MSRC_CONFIG_TIMEOUT_MACROP                  = 0x46,

    SOFT_RESET_GO2_SOFT_RESET_N                 = 0xBF,
    IDENTIFICATION_MODEL_ID                     = 0xC0,
    IDENTIFICATION_REVISION_ID                  = 0xC2,

    OSC_CALIBRATE_VAL                           = 0xF8,

    GLOBAL_CONFIG_VCSEL_WIDTH                   = 0x32,
    GLOBAL_CONFIG_SPAD_ENABLES_REF_0            = 0xB0,
    GLOBAL_CONFIG_SPAD_ENABLES_REF_1            = 0xB1,
    GLOBAL_CONFIG_SPAD_ENABLES_REF_2            = 0xB2,
    GLOBAL_CONFIG_SPAD_ENABLES_REF_3            = 0xB3,
    GLOBAL_CONFIG_SPAD_ENABLES_REF_4            = 0xB4,
    GLOBAL_CONFIG_SPAD_ENABLES_REF_5            = 0xB5,

    GLOBAL_CONFIG_REF_EN_START_SELECT           = 0xB6,
    DYNAMIC_SPAD_NUM_REQUESTED_REF_SPAD         = 0x4E,
    DYNAMIC_SPAD_REF_EN_START_OFFSET            = 0x4F,
    POWER_MANAGEMENT_GO1_POWER_FORCE            = 0x80,

    VHV_CONFIG_PAD_SCL_SDA__EXTSUP_HV           = 0x89,

    ALGO_PHASECAL_LIM                           = 0x30,
    ALGO_PHASECAL_CONFIG_TIMEOUT                = 0x30,
};

typedef enum { VcselPeriodPreRange, VcselPeriodFinalRange } vcselPeriodType;

uint8_t last_status; // status of last I2C transmission

typedef struct {
    bool tcc, msrc, dss, pre_range, final_range;
    // TCC: Target CentreCheck
    // MSRC: Minimum Signal Rate Check
    // DSS: Dynamic Spad Selection
} SequenceStepEnables;

typedef struct {
    uint16_t pre_range_vcsel_period_pclks, final_range_vcsel_period_pclks;

    uint16_t msrc_dss_tcc_mclks, pre_range_mclks, final_range_mclks;
    uint32_t msrc_dss_tcc_us,    pre_range_us,    final_range_us;
} SequenceStepTimeouts;

uint8_t address;
uint16_t io_timeout;
bool did_timeout;
uint16_t timeout_start_ms;
uint8_t stop_variable; // read by init and used when starting measurement; is StopVariable field of VL53L0X_DevData_t structure in API
uint32_t measurement_timing_budget_us;


/* * * * * * * * * * * * I2C Bus Read/Write Functions * * * * * * * * * * * */
I2C1_MESSAGE_STATUS I2C_Status = I2C1_MESSAGE_COMPLETE; // I2C Bus Status

void selectPort(muxPort_t sensorPort);
void selectPort2(uint8_t mux, uint8_t port); // select mux port
uint8_t getMuxCtrlReg(uint8_t mux);          // read interrupt values from mux
uint8_t getInterrupts(uint8_t mux);
void writeRegister(uint8_t dev, uint8_t reg, uint8_t data);
void writeRegister_16b(uint8_t dev, uint8_t reg, uint16_t data);
void writeRegister_32b(uint8_t dev, uint8_t reg, uint32_t data);
uint8_t readReg(uint8_t dev, uint8_t reg);
void readRegister(uint8_t dev, uint8_t reg, uint8_t* data);
uint16_t readRegister_16b(uint8_t dev, uint8_t reg);


/* * * * * * * * * * * * * * ToF Helper Functions * * * * * * * * * * * * * */
void initSingleToF(int ToF_num, uint16_t *dists);
void initAllToF(uint16_t *dists);
void initAllToF2(uint16_t *dists);
void getSingleToF(int ToF_num, uint16_t *dists);
void getAllToF(uint16_t *dists);
void getAllToF2(uint16_t *dists);
uint8_t getNearestObstacleIndex(uint16_t *dists);
uint8_t getNearestObstacleIndex2(uint16_t *dists);


/* * * * * * * * * * * Accelerometer Definitions * * * * * * * * * * */
//<Nick>
#define H3LIS200DL_I2CADDR 0x19
#define H3LIS200DL_WHO_AM_I 0x0F
#define H3LIS200DL_CTRL_REG1 0x20
#define H3LIS200DL_CTRL_REG2 0x21
#define H3LIS200DL_CTRL_REG3 0x22
#define H3LIS200DL_CTRL_REG4 0x23
#define H3LIS200DL_CTRL_REG5 0x24
#define H3LIS200DL_HP_FILTER_RESET 0x25
#define H3LIS200DL_REFERENCE 0x26
#define H3LIS200DL_STATUS_REG 0x27
#define H3LIS200DL_OUT_X_H 0x29               // X Data
#define H3LIS200DL_OUT_X_L 0x28
#define H3LIS200DL_OUT_Y_H 0x2B               // Y Data
#define H3LIS200DL_OUT_Y_L 0x2A
#define H3LIS200DL_OUT_Z_H 0x2D               // Z Data
#define H3LIS200DL_OUT_Z_L 0x2C
#define H3LIS200DL_INT1_CFG 0x30            // Interrupt 1 (Pin 11, used)
#define H3LIS200DL_INT1_SRC 0x31
#define H3LIS200DL_INT1_THS 0x32
#define H3LIS200DL_INT1_DURATION 0x33
#define H3LIS200DL_INT2_CFG 0x34            // Interrupt 2
#define H3LIS200DL_INT2_SRC 0x35
#define H3LIS200DL_INT2_THS 0x36
#define H3LIS200DL_INT2_DURATION 0x37
                                // POWER MODES
#define H3LIS200DL_PWR_DWN 0x00     // Power Down Mode
#define H3LIS200DL_NRML 0x01        // Normal Mode
#define H3LIS200DL_LP_0_5HZ 0x02    // Low Power 0.5Hz
#define H3LIS200DL_LP_1HZ 0x03      // Low Power 1.0Hz
#define H3LIS200DL_LP_2HZ 0x04      // Low Power 2.0Hz
#define H3LIS200DL_LP_5HZ 0x05      // Low Power 5.0Hz
#define H3LIS200DL_LP_10HZ 0x06     // Low Power 10.Hz
                                // OUTPUT DATA RATES
#define H3LIS200DL_DR_50HZ 0x00     // 50Hz
#define H3LIS200DL_DR_100HZ 0x01    // 100Hz
#define H3LIS200DL_DR_400HZ 0x02    // 400Hz
#define H3LIS200DL_DR_1000HZ 0x03   // 1000Hz

#define H3LIS200DL_EN_X 0x01    // Enable X Data
#define H3LIS200DL_EN_Y 0x02    // Enable Y Data
#define H3LIS200DL_EN_Z 0x04    // Enable Z Data
#define H3LIS200DL_EN_XYZ 0x07  // Enable X, Y, and Z Data


/* * * * * * * * * * * Accelerometer Function Definitions * * * * * * * * * * */
typedef enum {USE_I2C, USE_SPI} comm_mode;
typedef enum {POWER_DOWN, NORMAL, LOW_POWER_0_5HZ, LOW_POWER_1HZ,
                LOW_POWER_2HZ, LOW_POWER_5HZ, LOW_POWER_10HZ} power_mode;
typedef enum {DR_50HZ, DR_100HZ, DR_400HZ, DR_1000HZ} data_rate;
typedef enum {HPC_8, HPC_16, HPC_32, HPC_64} high_pass_cutoff_freq_cfg;
typedef enum {PUSH_PULL, OPEN_DRAIN} pp_od;
typedef enum {INT_SRC, INT1_2_SRC, DRDY, BOOT} int_sig_src;
typedef enum {LOW_RANGE, MED_RANGE, NO_RANGE, HIGH_RANGE} fs_range;
typedef enum {X_AXIS, Y_AXIS, Z_AXIS} int_axis;
typedef enum {TRIG_ON_HIGH, TRIG_ON_LOW} trig_on_level;

void H3LIS200DL_begin();
void H3LIS200DL_axesEnable(bool enable);
void H3LIS200DL_setPowerMode(power_mode pmode);
void H3LIS200DL_setODR(data_rate drate);
void H3LIS200DL_readAxes(int16_t* x, int16_t* y, int16_t* z);
uint8_t H3LIS200DL_readReg(uint8_t reg_address);
int16_t H3LIS200DL_convertToG(int16_t maxScale, int16_t reading);
void H3LIS200DL_setHighPassCoeff(high_pass_cutoff_freq_cfg hpcoeff);
void H3LIS200DL_enableHPF(bool enable);
void H3LIS200DL_HPFOnIntPin(bool enable, uint8_t pin);
void H3LIS200DL_intActiveHigh(bool enable);
void H3LIS200DL_intPinMode(pp_od _pinMode);
void H3LIS200DL_latchInterrupt(bool enable, uint8_t intSource);
void H3LIS200DL_intSrcConfig(int_sig_src src, uint8_t pin);
void H3LIS200DL_setFullScale(fs_range range);
bool H3LIS200DL_newXData();
bool H3LIS200DL_newYData();
bool H3LIS200DL_newZData();
void H3LIS200DL_enableInterrupt(int_axis axis, trig_on_level trigLevel,uint8_t interrupt, bool enable);
void H3LIS200DL_setIntDuration(uint8_t duration, uint8_t intSource);
void H3LIS200DL_setIntThreshold(uint8_t threshold, uint8_t intSource);
int16_t H3LIS200DL_Read_x(int16_t x);
int16_t H3LIS200DL_Read_y(int16_t y);
int16_t H3LIS200DL_Read_z(int16_t z);
//</Nick>
bool getAccelPoints(void);
bool getAccelPoints2(void);


/* * * * * * * * * * * SD Card Functions * * * * * * * * * * */
void writeTemplateToSD(void);
void writeAccelToSD(void);


/* * * * * * * * * * * Time-of-Flight Sensor Functions * * * * * * * * * * */
uint8_t VL53L0X_init(void);
bool VL53L0X_config(void);
bool VL53L0X_setSignalRateLimit(float limit_Mcps);
bool VL53L0X_getSpadInfo(uint8_t * count, bool * type_is_aperture);
uint32_t VL53L0X_getMeasurementTimingBudget(void);
void VL53L0X_getSequenceStepTimeouts(SequenceStepEnables const * enables, SequenceStepTimeouts * timeouts);
uint8_t VL53L0X_getVcselPulsePeriod(vcselPeriodType type);
bool VL53L0X_setMeasurementTimingBudget(uint32_t budget_us);
void VL53L0X_getSequenceStepEnables(SequenceStepEnables * enables);
uint16_t VL53L0X_encodeTimeout(uint16_t timeout_mclks);
bool VL53L0X_performSingleRefCalibration(uint8_t vhv_init_byte);
uint32_t VL53L0X_timeoutMclksToMicroseconds(uint16_t timeout_period_mclks, uint8_t vcsel_period_pclks);
uint32_t VL53L0X_timeoutMicrosecondsToMclks(uint32_t timeout_period_us, uint8_t vcsel_period_pclks);
uint16_t VL53L0X_decodeTimeout(uint16_t reg_val);
void VL53L0X_startContinuous(uint32_t period_ms);
void VL53L0X_stopContinuous(void);
uint16_t VL53L0X_readRangeContinuousMillimeters(void);
uint16_t VL53L0X_readRangeSingleMillimeters(void);
inline void VL53L0X_setTimeout(uint16_t timeout) { io_timeout = timeout; }
inline uint16_t VL53L0X_getTimeout(void) { return io_timeout; }
bool VL53L0X_timeoutOccurred(void);


/* * * * * * * * * * * * * * LED Display Functions * * * * * * * * * * * * * */
void showBinary(uint8_t n);
void showStartup(void);
void showStartupRGB(void);
void showDistanceRGB(uint16_t dist, LED_posn LED);
void showInitRGB(int index);
void showConcussion(void);
void showCount(void);
void showError(void);


/* * * * * * * * * * * * * Accelerometer Variables * * * * * * * * * * * * */
// <Nick>
int16_t x_1, y_1, z_1;
int16_t x_2, y_2, z_2;
int16_t x_3, y_3, z_3;
int16_t x_4, y_4, z_4;
int16_t x_5, y_5, z_5;
int16_t thresh = 50; // impact threshold (in Gs)) // set to 50 for actual use
int16_t max = 0x0000; // current maximum axis reading

// timestamps of readings
unsigned long timer1, timer2, timer3, timer4, timer5;

// c-strings for writing data to SD card
char data1[255];
char data2[255];
char data3[255];
char data4[255];
char data5[255];
// </Nick>

// set TRUE to automatically clear the interrupt of each ToF sensor upon reading
bool auto_int_clr = false;

/*
                         Main application
 */
int main(void) {
    /* * * * * * * * * * * * * * * ToF * * * * * * * * * * * * * * */
    address = VL53L0X_I2CADDR;
    io_timeout = 0;
    did_timeout = false;
    // distances from each ToF sensor
    int ToF_to_test = 2; // 0, 1, 2, 3, 4, 5
    uint8_t dist_8; // 8-bit integer used to display the 8 LSBs of distance
    uint16_t distances[NUM_TOF] = { 0xFFFF, 0xFFFF, 0xFFFF,
                                    0xFFFF, 0xFFFF, 0xFFFF};

    
    /* * * * * * * * * * * * * * * SETUP * * * * * * * * * * * * * * */
    SYSTEM_Initialize();    // MCC: I2C1, TMR1, SPI1 initialization
    Start_Initialization(); // for pins/LEDs
    I2C1_MESSAGE_STATUS I2C_Status = I2C1_MESSAGE_COMPLETE;
    
    //showStartup();    // run on-board LED startup pattern
    showStartupRGB();   // run RGB LED startup pattern
    
    //writeTemplateToSD();
    
    /* * * * * * * * * * * * * * ToF Setup * * * * * * * * * * * * * */
//    initSingleToF(ToF_to_test, distances); // initialize a single ToF sensor
    initAllToF(distances); // initialize all ToF sensors
    uint8_t index; // hold the index of the sensor detecting the nearest object

    
    /* * * * * * * * * * * Accelerometer Setup * * * * * * * * * * */
    selectPort2(0x00, 0x03); // select Accelerometer port (Mux 0, Port 3)
    H3LIS200DL_begin();
    msTimerDelay(5);
    
    while (1) {
        
        /* * * * * * * * * * * * * * Accelerometer * * * * * * * * * * * * * */
        if(getAccelPoints2()) { // get accel data, returns true if max >= thresh
            writeAccelToSD();
        }
        
        /*************** I2C Time-of-Flight **************/
        getAllToF(distances);      // get the distances from all ToF sensors
        
        // get the distance from the ToF_to_test sensor
//        getSingleToF(ToF_to_test, distances);

        /************** SHOW READING **************/
//        dist_8 = distances[ToF_to_test] & 0xFF;
        // show reading LSBs via on-board LEDs
//        showBinary(dist_8); 
//        msTimerDelay(10);
        // show RGB corresponding to reading of ToF_to_test
//        showDistanceRGB(distances[ToF_to_test], LEDs[ToF_to_test]);
        
        // find the sensor detecting the closest obstacle
        index = getNearestObstacleIndex(distances);
        // show RGB corresponding to reading of said sensor
        if(index == 0xFF) {
            showBinary(0x00);
        }
        else {
            showDistanceRGB(distances[index], LEDs[index]);
        }

    }
    return 0; 
}

// displays the byte value in binary on the LEDs
void showBinary(uint8_t n) {
    LED1 = n;
    LED2 = n >> 1;
    LED3 = n >> 2;
    LED4 = n >> 3;
    LED5 = n >> 4;
    LED6 = n >> 5;
    LED7 = n >> 6;
    LED8 = n >> 7;
}

// a fun visual to do at boot
void showStartup(void) {
    uint16_t delay = 25;
    
    uint8_t display = 0x01;
    while(display != 0x80) {     // run one LED "up"
        display = display << 1;
        showBinary(display);
        msTimerDelay(delay);
    }
    while(display > 0x00) {     // run one LED back "down"
        display = display >> 1;
        showBinary(display);
        msTimerDelay(delay);
    }
    
    display = 0x00;             // reset to 0
    while(display < 0xFF) {     // "fill" LEDs
        display = display << 1;
        showBinary(++display);
        msTimerDelay(delay);
    }
    while(display > 0x00) {     // "empty" LEDs
        display = display >> 1;
        showBinary(display);
        msTimerDelay(delay);
    }
    
}

void showStartupRGB(void) {
    uint16_t delay = 200;
    
    showBinary(LR_RED | LR_ON | MID_RED);
    msTimerDelay(delay);
    
    showBinary(LR_PRP | LR_ON | MID_PRP);
    msTimerDelay(delay);

    showBinary(LR_BLU | LR_ON | MID_BLU);
    msTimerDelay(delay);
    
    showBinary(LR_BLU | LR_GRN | LR_ON | MID_BLU | MID_GRN);
    msTimerDelay(delay);

    showBinary(LR_GRN | LR_ON | MID_GRN);
    msTimerDelay(delay);
}

void showDistanceRGB(uint16_t dist, LED_posn LED) {
    if(1900 < dist) {
        showBinary(0x00);
    }
    else if(LED == LED_C) {
        if(dist <= 500) {
            showBinary(MID_RED);
        } else if(500 < dist && dist <= 1000) {
            showBinary(MID_GRN);
        } else if(1000 < dist && dist <= 1500) {
            showBinary(MID_BLU);
        }
    }
    else if(LED == LED_L) {
        if(dist <= 500) {
            showBinary(LR_RED | R_OFF);
        } else if(500 < dist && dist <= 1000) {
            showBinary(LR_GRN | R_OFF);
        } else if(1000 < dist && dist <= 1500) {
            showBinary(LR_BLU | R_OFF);
        }
    }
    else if(LED == LED_R) {
        if(dist <= 500) {
            showBinary(LR_RED | L_OFF);
        } else if(500 < dist && dist <= 1000) {
            showBinary(LR_GRN | L_OFF);
        } else if(1000 < dist && dist <= 1500) {
            showBinary(LR_BLU | L_OFF);
        }
    }
}

void showInitRGB(int index) {
    int clr = index % 3; // determines what color to turn the LED
        // 0 -> RED
        // 1 -> YELLOW
        // 2 -> WHITE
    
    if(index < (NUM_TOF/2)) { // left side sensors
        if(clr == 0) {
            showBinary(LR_RED | R_OFF); // red
        } else if(clr == 1) {
            showBinary(LR_RED | LR_GRN | R_OFF); // yellow
        } else if(clr == 2) {
            showBinary(LR_RED | LR_GRN | LR_BLU | R_OFF); // white
        }
    }
    else if(( (NUM_TOF/2) <= index ) && ( index < NUM_TOF )) { // right side sensors
        if(clr == 0) {
            showBinary(LR_RED | L_OFF); // red
        } else if(clr == 1) {
            showBinary(LR_RED | LR_GRN | L_OFF); // yellow
        } else if(clr == 2) {
            showBinary(LR_RED | LR_GRN | LR_BLU | L_OFF); // white
        }
    }
}
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

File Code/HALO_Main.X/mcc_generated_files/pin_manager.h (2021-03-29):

/**
  PIN MANAGER Generated Driver File

  @Company:
    Microchip Technology Inc.

  @File Name:
    pin_manager.h

  @Summary:
    This is the generated manager file for the PIC24 / dsPIC33 / PIC32MM MCUs device.  This manager
    configures the pins direction, initial state, analog setting.
    The peripheral pin select, PPS, configuration is also handled by this manager.

  @Description:
    This source file provides implementations for PIN MANAGER.
    Generation Information :
        Product Revision  :  PIC24 / dsPIC33 / PIC32MM MCUs - 1.170.0
        Device            :  dsPIC33EP512GM706
    The generated drivers are tested against the following:
        Compiler          :  XC16 v1.61
        MPLAB 	          :  MPLAB X v5.45
*/

/*
    (c) 2020 Microchip Technology Inc. and its subsidiaries. You may use this
    software and any derivatives exclusively with Microchip products.

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
    IN NO EVENT WILL MICROCHIP BE LIABLE FOR ANY INDIRECT, SPECIAL, PUNITIVE,
    INCIDENTAL OR CONSEQUENTIAL LOSS, DAMAGE, COST OR EXPENSE OF ANY KIND
    WHATSOEVER RELATED TO THE SOFTWARE, HOWEVER CAUSED, EVEN IF MICROCHIP HAS
    BEEN ADVISED OF THE POSSIBILITY OR THE DAMAGES ARE FORESEEABLE. TO THE
    FULLEST EXTENT ALLOWED BY LAW, MICROCHIP'S TOTAL LIABILITY ON ALL CLAIMS IN
    ANY WAY RELATED TO THIS SOFTWARE WILL NOT EXCEED THE AMOUNT OF FEES, IF ANY,
    THAT YOU HAVE PAID DIRECTLY TO MICROCHIP FOR THIS SOFTWARE.

    MICROCHIP PROVIDES THIS SOFTWARE CONDITIONALLY UPON YOUR ACCEPTANCE OF THESE
    TERMS.
*/

#ifndef _PIN_MANAGER_H
#define _PIN_MANAGER_H
/**
    Section: Includes
*/
#include <xc.h>

/**
    Section: Device Pin Macros
*/
/**
  @Summary
    Sets the GPIO pin, RA4, high using LATA4.

  @Description
    Sets the GPIO pin, RA4, high using LATA4.

  @Preconditions
    The RA4 must be set to an output.

  @Returns
    None.

  @Param
    None.

  @Example
    <code>
    // Set RA4 high (1)
    SDO1_SetHigh();
    </code>

*/
#define SDO1_SetHigh()          (_LATA4 = 1)
/**
  @Summary
    Sets the GPIO pin, RA4, low using LATA4.

  @Description
    Sets the GPIO pin, RA4, low using LATA4.

  @Preconditions
    The RA4 must be set to an output.

  @Returns
    None.

  @Param
    None.

  @Example
    <code>
    // Set RA4 low (0)
    SDO1_SetLow();
    </code>

*/
#define SDO1_SetLow()           (_LATA4 = 0)
/**
  @Summary
    Toggles the GPIO pin, RA4, using LATA4.

  @Description
    Toggles the GPIO pin, RA4, using LATA4.

  @Preconditions
    The RA4 must be set to an output.

  @Returns
    None.

  @Param
    None.

  @Example
    <code>
    // Toggle RA4
    SDO1_Toggle();
    </code>

*/
#define SDO1_Toggle()           (_LATA4 ^= 1)
/**
  @Summary
    Reads the value of the GPIO pin, RA4.

  @Description
    Reads the value of the GPIO pin, RA4.

  @Preconditions
    None.

  @Returns
    None.

  @Param
    None.

  @Example
    <code>
    uint16_t portValue;

    // Read RA4
    postValue = SDO1_GetValue();
    </code>

*/
#define SDO1_GetValue()         _RA4
/**
  @Summary
    Configures the GPIO pin, RA4, as an input.

  @Description
    Configures the GPIO pin, RA4, as an input.

  @Preconditions
    None.

  @Returns
    None.

  @Param
    None.

  @Example
    <code>
    // Sets the RA4 as an input
    SDO1_SetDigitalInput();
    </code>

*/
#define SDO1_SetDigitalInput()  (_TRISA4 = 1)
/**
  @Summary
    Configures the GPIO pin, RA4, as an output.

  @Description
    Configures the GPIO pin, RA4, as an output.

  @Preconditions
    None.

  @Returns
    None.

  @Param
    None.

  @Example
    <code>
    // Sets the RA4 as an output
    SDO1_SetDigitalOutput();
    </code>

*/
#define SDO1_SetDigitalOutput() (_TRISA4 = 0)
/**
  @Summary
    Sets the GPIO pin, RA9, high using LATA9.

  @Description
    Sets the GPIO pin, RA9, high using LATA9.

  @Preconditions
    The RA9 must be set to an output.

  @Returns
    None.

  @Param
    None.

  @Example
    <code>
    // Set RA9 high (1)
    SDI1_SetHigh();
    </code>

*/
#define SDI1_SetHigh()          (_LATA9 = 1)
/**
  @Summary
    Sets the GPIO pin, RA9, low using LATA9.

  @Description
    Sets the GPIO pin, RA9, low using LATA9.

  @Preconditions
    The RA9 must be set to an output.

  @Returns
    None.

  @Param
    None.

  @Example
    <code>
    // Set RA9 low (0)
    SDI1_SetLow();
    </code>

*/
#define SDI1_SetLow()           (_LATA9 = 0)
/**
  @Summary
    Toggles the GPIO pin, RA9, using LATA9.

  @Description
    Toggles the GPIO pin, RA9, using LATA9.

  @Preconditions
    The RA9 must be set to an output.

  @Returns
    None.

  @Param
    None.

  @Example
    <code>
    // Toggle RA9
    SDI1_Toggle();
    </code>

*/
#define SDI1_Toggle()           (_LATA9 ^= 1)
/**
  @Summary
    Reads the value of the GPIO pin, RA9.

  @Description
    Reads the value of the GPIO pin, RA9.

  @Preconditions
    None.

  @Returns
    None.

  @Param
    None.

  @Example
    <code>
    uint16_t portValue;

    // Read RA9
    postValue = SDI1_GetValue();
    </code>

*/
#define SDI1_GetValue()         _RA9
/**
  @Summary
    Configures the GPIO pin, RA9, as an input.

  @Description
    Configures the GPIO pin, RA9, as an input.

  @Preconditions
    None.

  @Returns
    None.

  @Param
    None.

  @Example
    <code>
    // Sets the RA9 as an input
    SDI1_SetDigitalInput();
    </code>

*/
#define SDI1_SetDigitalInput()  (_TRISA9 = 1)
/**
  @Summary
    Configures the GPIO pin, RA9, as an output.

  @Description
    Configures the GPIO pin, RA9, as an output.

  @Preconditions
    None.

  @Returns
    None.

  @Param
    None.

  @Example
    <code>
    // Sets the RA9 as an output
    SDI1_SetDigitalOutput();
    </code>

*/
#define SDI1_SetDigitalOutput() (_TRISA9 = 0)
/**
  @Summary
    Sets the GPIO pin, RB0, high using LATB0.

  @Description
    Sets the GPIO pin, RB0, high using LATB0.

  @Preconditions
    The RB0 must be set to an output.

  @Returns
    None.

  @Param
    None.

  @Example
    <code>
    // Set RB0 high (1)
    SDCard_CS_SetHigh();
    </code>

*/
#define SDCard_CS_SetHigh()          (_LATB0 = 1)
/**
  @Summary
    Sets the GPIO pin, RB0, low using LATB0.

  @Description
    Sets the GPIO pin, RB0, low using LATB0.

  @Preconditions
    The RB0 must be set to an output.

  @Returns
    None.

  @Param
    None.

  @Example
    <code>
    // Set RB0 low (0)
    SDCard_CS_SetLow();
    </code>

*/
#define SDCard_CS_SetLow()           (_LATB0 = 0)
/**
  @Summary
    Toggles the GPIO pin, RB0, using LATB0.

  @Description
    Toggles the GPIO pin, RB0, using LATB0.

  @Preconditions
    The RB0 must be set to an output.

  @Returns
    None.

  @Param
    None.

  @Example
    <code>
    // Toggle RB0
    SDCard_CS_Toggle();
    </code>
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

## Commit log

2021-03-18 Added accelerometer code
2021-04-03 Functioning ToF and RGB LED code.

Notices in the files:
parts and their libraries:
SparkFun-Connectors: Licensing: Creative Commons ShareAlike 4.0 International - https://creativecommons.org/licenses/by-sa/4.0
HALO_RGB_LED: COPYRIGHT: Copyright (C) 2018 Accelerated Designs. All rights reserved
